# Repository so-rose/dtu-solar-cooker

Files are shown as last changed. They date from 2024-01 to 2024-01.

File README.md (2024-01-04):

# Solar Cooker
This is the repository for the project at the center of the DTU course 47203.
Highly WIP.

## Project Plan
See `design/plan.qmd` for GANTT chart and updated TODO list.

## Design
For design-phase, see `design/main.qmd`.
This is a Python-based Quarto document, which should also be readable as plain-text.

# Contributing
This project uses Quarto (<https://quarto.org/>), a FOSS tool for easily creating high-quality, reproducible, interactive documents, slideshows, websites, and more.

Quarto is cross-platform and integrates cleanly with many text editors.
If in doubt, try RStudio or VSCode.
See <https://quarto.org/docs/get-started/>

## Getting Started with Quarto
Quarto brings together the functionality of Jupyter notebooks, LaTeX mathematics typesetting, embeddable languages for ex. diagramming (<https://mermaid.js.org/syntax/gantt.html>), and automatic high-quality output to web, pdf, and many more.

This is all exposed using an almost-Markdown text format `.qmd`.

If any of this sounds familiar, it should be possible to be productive in Quarto within an hour:

- <https://quarto.org/docs/get-started/hello/text-editor.html>
- <https://quarto.org/docs/get-started/computations/text-editor.html>
- <https://quarto.org/docs/get-started/authoring/text-editor.html>

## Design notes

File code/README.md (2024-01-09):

# No-IDE Arduino

Works with Debian 11.

Install with
```bash
git clone --recurse-submodules https://github.com/so-rose/dtu-solar-cooker.git
```

# Setup
This project uses "Arduino Makefile" (<https://github.com/sudar/Arduino-Makefile>) to simplify cross-compiling and uploading `.ino` into a format supported by 
## Setup (Debian)
Install `arduino-mk` using:
```bash
sudo apt install arduino-mk
```

## Setup (Other)

For platform-specific configuration details, change the Makefile variables according to <https://github.com/sudar/Arduino-Makefile#usage>.

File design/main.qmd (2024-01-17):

---
title: "Solar Cooker Design"
date: "2024-01-01"
abstract: |
  Prototyping design for a solar cooker.
author:
  - name: Sofus Albert Høgsbro Rose (s174509)
    email: s174509@dtu.dk
    affiliation: 
      - name: Technical University of Denmark
        city: Kongens Lyngby
        url: dtu.dk

format:
  html:
    toc: true
    code-fold: true
    embed-resources: true
    #self-contained-math: true
    execute:
      output: "asis"
      warning: false
  pdf:
    toc: true
    execute:
      echo: false
      warning: false
      panel: "center"
---
\newpage

```{python}
from __future__ import annotations
from typing import Callable, Union
import itertools
import contextlib
from functools import reduce
from dataclasses import dataclass

import scipy as sc
import sympy as sp
import sympy.physics.units as spu
import numpy as np
import pandas as pd

import spb
import holoviews as hv
import hvplot.pandas

# HoloViews Configuration
hv.extension("matplotlib", logo=False)
hv.notebook_extension(display_formats=['html','png'])

# Sympy Printing Configuration
from IPython.display import display, display_latex
def disp(
	*exprs,
	numbering: bool = False,
	align_on: str | None = None,
):
	if align_on is not None:
		exprs_latex = (
			("\\begin{equation}" if numbering else "\\begin{equation*}")
			+ "\\begin{aligned}"
			+ "\\\\".join([
				sp.latex(
					expr,
					mode="plain"
				).replace(align_on, f" & {align_on}")
				for expr in exprs
			])
			+ "\\end{aligned}"
			+ ("\\end{equation}" if numbering else "\\end{equation*}")
		)

	else:
		exprs_latex = "\n\n".join([
			sp.latex(
				expr,
				mode="equation" if numbering else "equation*",
			)
			for expr in exprs
		])

	display_latex(exprs_latex, raw=True)
```

# General Design
The goal is to design a device, with the dimensions 300x300x300, which effectively uses solar light energy to heat water.

We will use a parabolic reflector to focus the maximal area of incoming solar power density onto a surface bounded by coiled water tubes.

# Design of Parabolic Reflector
We define the paraboloid reflector parametrically
```{python}
def paraboloid(
    u: sp.Symbol,
    theta: sp.Symbol,
    radius: float,
    height: float,
):
    return sp.Matrix([
        radius * sp.sqrt(u / height) * sp.cos(theta),
        radius * sp.sqrt(u / height) * sp.sin(theta),
        u,
    ])
```
and state its general form:
```{python}
u = sp.Symbol("u", real=True, positive=True)
theta = sp.Symbol("theta", real=True, positive=True)

disp(
    paraboloid(u, theta, sp.Symbol("r"), sp.Symbol("h"))
)
```

Our bounding box is $300 \text{mm}^3$, which we plug in directly as the diameter of the top ring
```{python}
#| echo: true

bound_side_length = spu.convert_to(
    300 * spu.mm,
    spu.meter,
)

diameter_reflector = bound_side_length
diameter_reflector_SI = diameter_reflector / spu.meter
height_reflector = bound_side_length / 8
disp(height_reflector)
```
and use to compute the particular parameterization of the reflector we need:
```{python}
# Computed
radius_reflector = diameter_reflector / 2

reflector = paraboloid(
    u,
    theta,
    radius_reflector / spu.meter,
    height_reflector / spu.meter,
)
disp(reflector)
```

The "focus point"
```{python}
height_focus_point = radius_reflector**2 / (4*height_reflector)
focus_point_reflector = sp.Matrix([
    0,
    0,
    height_focus_point,
])
disp(focus_point_reflector.n())
```
describes the destination point of all light reflected by the paraboloid.

Finally, we plot our desired reflector, with a small sphere around the focus point:
```{python}
u_s, v_s = sp.symbols("u_s v_s")
spb.graphics(
	spb.surface_parametric(
			*reflector,
			(u, 0, height_reflector / spu.meter),
			(theta, 0, 2*sp.pi),
			"expr",
			n=50,
	),
	spb.surface_parametric(
		focus_point_reflector[0] + (_r:=0.008) * sp.cos(u_s) * sp.sin(v_s),
		focus_point_reflector[1] + _r * sp.sin(u_s) * sp.sin(v_s),
		focus_point_reflector[2] / spu.meter + _r * sp.cos(v_s),
		(u_s, 0, 2*sp.pi),
		(v_s, 0, 2*sp.pi),
		"expr",
		n=20,
	),
	show=True,
	backend=spb.KB,
)
```

*We presume a choice of coordinate system that places the sun, a perfect directional light, directly above this construction.*

## Trapezoidal Discretization
To actually cheaply manufacture this mirror, we must create a discretization of this paraboloid into a number of small trapezoids.

In practice, we will cut/fabricate the trapezoids at this particular size, and attach precisely cut household Al foil (a cheap, non-rough, highly reflective material) to them. Then, they will be mounted into predefined elements of the paraboloid print.

Design TBD

# Energy Transfer
We describe the energy transfer properties, including the design of the heating container.

We introduce two variables to describe the (max) diameter of the heating container, and the flux power density of the solar light.
```{python}
diameter_container = sp.Symbol(
    "d_c", real=True, positive=True,
) * spu.meter
diameter_container_SI = diameter_container / spu.meter
#diameter_container = (diameter_reflector/8)
radius_container = diameter_container / 2

intensity_solar = sp.Symbol(
    "I_s", real=True, positive=True,
) * spu.watt/spu.meter**2  ## Surface Power Density
intensity_solar_SI = intensity_solar / (spu.watt/spu.meter**2)

## See the Solar Constant:
# - https://en.wikipedia.org/wiki/Solar_constant
# - https://en.wikipedia.org/wiki/Surface_power_density

disp(diameter_container / spu.meter, intensity_solar_SI)
```

## Design of Heating Container
We want our container to evenly receive heat energy reflected by the paraboloid reflector.
Thus, we define it to also be a paraboloid.

This method minimizes energy loss down to three primary sources:
- Shading due to the container blocking part of the parabolic reflector.
- Non-reflected light by the reflector.
- Non-absorbed light at the boundary of the container.

First, we define the actual area which is actively collecting solar energy as the "non-masked collection area":
```{python}
#| echo: true
total_collection_area = sp.pi * radius_reflector**2
masked_collection_area = sp.pi * radius_container**2

unmasked_collection_area = total_collection_area - masked_collection_area 

total_collection_power = sp.simplify(
	intensity_solar * total_collection_area
)

disp(
    unmasked_collection_area.n(2)
)
```

We use the unmasked collection area to compute the total power transmitted, in terms of the "solar constant" $I_s$ (**NOTE: This is some kind of integral of the sun's spectral power distribution.**)
```{python}
total_power = sp.simplify(
    intensity_solar * unmasked_collection_area * (2/3)
)
disp(
    sp.Eq(
        sp.Symbol("P_s"),
        total_power,
    )
)
```

Reasonably speaking, the **wattage per square meter** transmitted by the sun (aka. the value for $I_s$) can be fixed to $1.361\  \text{kWh}/\text{m}^2$.
This results in the following total incident solar power, as a function of the heating container diameter:
```{python}
disp(
    sp.Eq(
        sp.Function("P_s")(diameter_container_SI),
        total_power.subs({
					intensity_solar_SI: 1361, #spu.watt/spu.meter**2
					#diameter_container_SI: 0.08,
				}).n(),
    )
)
```

## Choice of Container Diameter
Small diameters are hard to work with in practice - but large diameters block too much power.
There is a subjectiveness to what the ideal choice.

Here's the graph of **wattage** as a function of container diameter:
```{python}
%matplotlib inline
spb.plot(
	total_power.subs({
		intensity_solar_SI: 1361, #spu.watt/spu.meter**2
	}) / spu.watt,
	(diameter_container_SI, 0, diameter_reflector_SI),
	show=True
)
```

Here's the graph of **retained energy factor** (percent/100) based on container diameter:
```{python}
%matplotlib inline
spb.plot(
	(total_power / total_collection_power).subs({
		intensity_solar_SI: 1361, #spu.watt/spu.meter**2
	}),
	(diameter_container_SI, 0, diameter_reflector_SI),
	show=True
)
```

Since we have **1/8 inch copper tubes** ($0.3175 \text{cm}$) available to us, we are not constrained by what we're wrapping around the heating container.

Thus, we select $5 \text{cm}$ as a reasonable tradeoff of fabrication simplicity relative to power loss.
The total incident power power at this value becomes:
```{python}
disp(
    sp.Eq(
        sp.Function("P_s")(3 * spu.cm),
        total_power.subs({
					intensity_solar_SI: 1361, #spu.watt/spu.meter**2
					diameter_container_SI: 0.03,
				}).n(),
    )
)
```

The retained power after shading using this choice of container diameter is just over 97 percent:
```{python}
diameter_container_chosen = 0.03 * spu.meter

disp(
	(total_power / total_collection_power).subs({
		intensity_solar_SI: 1361, #spu.watt/spu.meter**2
		diameter_container_SI: 0.05,
	}) * 100 * spu.percent
)
```

## Solving for the Container Height
Where exactly should the container sit?

First, we compute the angle from the upper ring of the reflector to the focus point
```{python}
angle_to_focus = sp.atan(
	(height_focus_point - height_reflector)
	/ radius_reflector
)
```

This angle can be used to form a right triangle between any edge point on the top reflector ring, the focus point, and the center of the reflector ring.

The height of this right triangle is the height of the ring.
Trigonometrically, it can be setup as
```{python}
height_container = sp.simplify(
	sp.tan(angle_to_focus) * (
		(diameter_reflector - diameter_container) / 2
	)
)

disp(height_container)
```
which computes out to
```{python}
chosen_height_container = height_container.subs({
	diameter_container_SI: sp.nsimplify(0.05),
})
disp(
	chosen_height_container.n()
)
```

Finally, when setting up the parameterization of the heating container, the container needs to be shifted up by the difference between the focus point and the reflector height.
```{python}
shift_reflector_to_container = height_focus_point - height_reflector
```

With this information, we create the paraboloid representing the container
```{python}
container = paraboloid(
    u,
    theta,
    2*radius_container / spu.meter,
    height_container / spu.meter,
) + sp.Matrix([
	0,
	0,
	shift_reflector_to_container / spu.meter,
])
disp(container)
```
chosen specifically to be
```{python}
chosen_container = container.subs({
	diameter_container_SI: sp.nsimplify(diameter_container_chosen/spu.meter),
})
disp(chosen_container)
```
and plot it visually:
```{python}
spb.plot3d_parametric_surface(
    list(reflector),
    list(chosen_container),
    (u, 0, height_reflector / spu.meter), (theta, 0, 2*sp.pi), "expr",
    n=50,
    backend=spb.KB,
)
```

## Computing Wire Properties
**TBD: Fix height of coil, compute wire length, compute contained volume.**

As mentioned, the wire in use is **1/8 inch copper tubes** ($0.3175 \text{cm}$).

Considering only the center of this wire for a moment, we parameterize it as a 1D curve:
```{python}
chosen_diameter_container_SI = sp.nsimplify(0.05)
chosen_radius_container_SI = chosen_diameter_container_SI/2

chosen_radius_container = chosen_radius_container_SI * spu.meter

coil_diameter = sp.nsimplify(0.05) * spu.meter
wire_diameter = spu.convert_to(
	sp.nsimplify(0.3175) * spu.cm,
	spu.meter,
)
wire_radius = wire_diameter / 2

chosen_container_radius = spu.meter * (
	chosen_diameter_container_SI/2 - sp.sqrt(
		chosen_container[0]**2
		+ chosen_container[1]**2
	).subs({
		u: (
			chosen_height_container + height_reflector
		) / spu.meter + (
			wire_diameter * u/(2*sp.pi)
		) / spu.meter
	}).simplify()
)

u = sp.Symbol("u", real=True, positive=True)
v = sp.Symbol("v", real=True, positive=True)
coiled_wire_surface = sp.simplify(
	sp.Matrix([
		chosen_container_radius*sp.cos(u) + (
			wire_radius*sp.cos(u)*sp.cos(v)
		),
		chosen_container_radius*sp.sin(u) + (
			wire_radius*sp.sin(u)*sp.cos(v)
		),
		chosen_height_container+height_reflector + (
			wire_diameter * u/(2*sp.pi)
		) + (
			wire_radius * sp.sin(v)
		),
	]) / spu.meter
)
disp(coiled_wire_surface)

spb.graphics(
	spb.surface_parametric(
		*reflector,
		(u, 0, height_reflector / spu.meter),
		(theta, 0, 2*sp.pi),
		"expr",
		n=50,
	),
	spb.surface_parametric(
		focus_point_reflector[0] + (_r:=0.004) * sp.cos(u_s) * sp.sin(v_s),
		focus_point_reflector[1] + _r * sp.sin(u_s) * sp.sin(v_s),
		focus_point_reflector[2] / spu.meter + _r * sp.cos(v_s),
		(u_s, 0, 2*sp.pi),
		(v_s, 0, 2*sp.pi),
		"expr",
		n=20,
	),
	spb.surface_parametric(
		*chosen_container,
		(u, 0, height_reflector / spu.meter),
		(theta, 0, 2*sp.pi),
		"expr",
		n=100,
	),
	spb.surface_parametric(
		*coiled_wire_surface,
		(u, 0, 10*sp.pi), (v, 0, 10*sp.pi), "expr",
		n=100,
	),
	backend=spb.KB,
)
```

# Pressure Flow Rate

We compute the water pressure
```{python}

```

# Fabrication Procedure
- [x] Compute required length of 1/8 inch copper tubing for wrapping around, including space for outlet and inlet.
- [x] Compute volume contained within each segment of tubing, aka. measure the thickness.
- [x] Compute number and size of mirror (glass) trapezoids.
- [x] Compute printable geometry for the reflector, including slots for inserting trapezoid mirrors, including a mounting mechanism for the container, including a hole in the bottom for water outlet, and possibly including a doughnut-shaped spot for upper water storage.
- [x] Compute printable geometry for the container, including slots for the tubing and the mounting mechanism.
- [x] Compute a heatmap on the container of areas where trapezoid-reflected solar intensities are non-uniform (as the perfect curve)
- [ ] Correct actual power transferred to water in each region of tubing, considering the simulated trapezoidal discretization.
- [x] Choose an adhesive (?) effective for the mirrors and for the tubes, which can handle temperatures up to 125C.
- [ ] Determine a mechanism for flow control at the outlet, ex. software flow control?

- [ ] Fabricate the mirror, container, water containers, and try mounting it all.
- [ ] Try running water through the entire mechanism, to make sure it can do that.
- [ ] Spray-paint the tubing black (if it isn't already absorbive).

- [ ] Include computations describing the efficiency of the reflector and the efficiency of the absorbive copper tubing.
	- [ ] Can we borrow a spectrometer to characterize the two materials we end up with? Maybe even at the particular incident angles?

- [ ] Try a FEM simulation of the final setup to solve for heat transfer over time.

*Maybe we should just give the reflector feet and just pseudo-submerse it in the lower water collector?*

*The water container could also be a 3D-printed thing; however, it will need waterproofing. Much better idea; it could be better to just use something normal. Literally a plastic bag or bowl or something.*

*How will we know it works? 0.5L of water at 21C would, over the course of 15minutes, require 79 watts to reach a temperature of 55C. Since we know the incident wattage as solar light intensity, the final temperature will tell us how we did in terms efficiency.*

After print
- [ ] Another motor for the flow rate
- [ ] Empirically measure
- [ ] Print an output flow control

- [ ] Cold water towers (cans?)
- [ ] Hot water container
Don't boil things!

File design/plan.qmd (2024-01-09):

---
title: "Solar Cooker Project Planning"
date: "2024-01-04"
abstract: |
  Our approach to the Solar Cooker project.
#author:
#  - name: Sofus Albert Høgsbro Rose (s174509)
#    email: s174509@dtu.dk
#    affiliation: 
#      - name: Technical University of Denmark
#        city: Kongens Lyngby
#        url: dtu.dk

format:
  html:
    toc: true
    code-fold: true
    embed-resources: true
    #self-contained-math: true
    execute:
      output: "asis"
      warning: false
  pdf:
    toc: true
    execute:
      echo: false
      warning: false
      panel: "center"
  ipynb:
    toc: true
    execute:
      echo: true
      warning: false
---
\newpage

# GANTT Chart
This is the overarching plan (group )
```{mermaid}
gantt
    title Design-Build 3 Plan
    dateFormat YYYY-MM-DD
    section Simulation
        Design :2023-01-01, 3d
        Thermal :2d
        MVP Validation :2023-01-07, 2d
        Validation :2023-01-12, 4d
    section Fabrication
        Geometry :2023-01-05, 1d
        MVP :3d
        Production :5d
    section Control
        Temp :2023-01-08, 2d
        Shaders :2d
        Instrument :2023-01-09, 5d
    section Report
        Preliminary :2023-01-02, 7d
        Body :7d
        Polish :2d
        Exam :1d
```

# Big Plan
**Simulation**

- [ ] Design: How is it going to work? From first principles.
- [ ] Thermal Simulation: Execute a heat transfer simulation.
- [ ] MVP Validation: Validate that the simulation (and presumptions therein) was done accurately.
- [ ] Validation: Validate that the simulation (and presumptions therein) was done accurately.

**Fabrication**

- [ ] Geometry: Design the 3D-printable model.
- [ ] MVP: Fabricate a first attempt, which should work minimally. **Test with artificial sun at the end**.
- [ ] Production: Fabricate the final product.

**Control**

- [ ] Temperature Sensor: Install the temperature sensor.
- [ ] Shaders: Install the shader control.
- [ ] Instrument: Instrument real-time data, for internal use and for export / graphing.

**Report**

- [ ] Preliminary: The design document (`.qmd`) will later become the report.
- [ ] Body: Writing happens parallel to post-MVP refinements.
- [ ] Polish: Refine report and produce a slideshow variant.
- [ ] Exam: Final preparations and exam.

## Fabrication List
- [ ] Reflector: High-R parabolic shape.
- [ ] Container: Internal parabolic boundary is 3D-printed, around which liquid tubes are wrapped, which in turn are painted with a high-A material that minimizes blackbody radiation loss.
- [ ] Fabrication Device

## Shopping List
- [ ] 1/8 Inch Copper Tube
- [ ] Black Spray Paint

- [ ] Exact knife
- [ ] Spray glue

- [ ] Cold water tower
- [ ] Hot water container

- [ ] Funnel (for flow test)

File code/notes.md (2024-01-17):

# Experiment 0
`experiment_0`: Cold water temperature.

# Experiment 1
`experiment_1`: Hot water temperature (full flow) after heating for 1min

Pre-Measure:
- Cold water temp
- Hot water temp

Procedure:
- Plug Outlet w/Plug
- Video Start
- Fill 20mL Fluid into Cold Water Container
- Insert Thermometer into Hot Water Container water temperature
- Simultaneously:
	- Insert Contraption
	- Start Timer
	- Close Hood
- @ Timer=1min
	- Open Hood
	- Remove Contraption
	- Stop Timer
	- Close Hood
- Simultaneously:
	- Start Thermometer Recording
	- Unplug Outlet
	- Start Timer
- @ Water Flow Done
	- Stop Timer

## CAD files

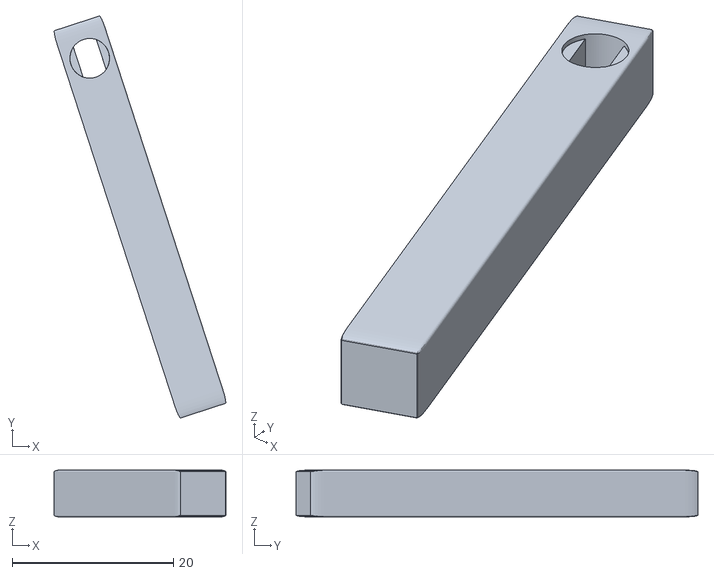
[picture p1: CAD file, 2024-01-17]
prints/lever/lever_2.stl
21.3 x 49.9 x 5.80

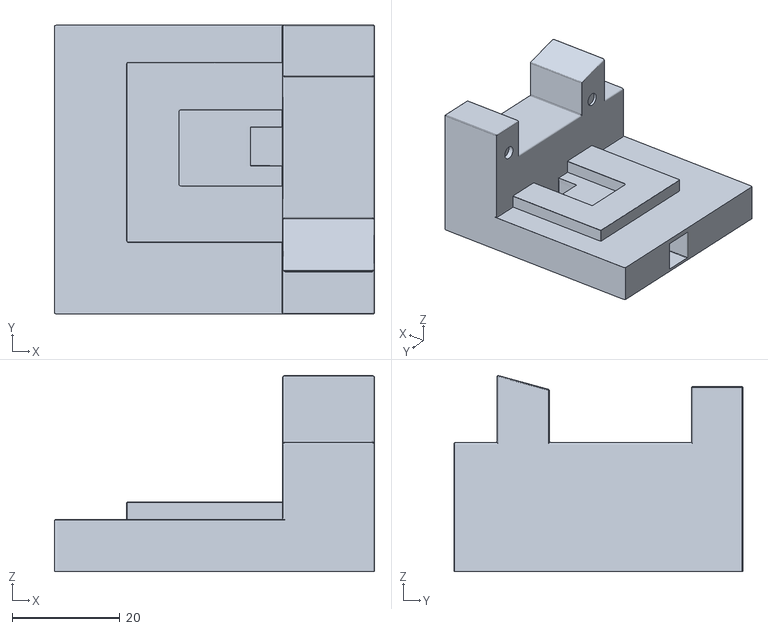
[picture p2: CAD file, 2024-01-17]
prints/mount/mount_1.stl
59.3 x 53.6 x 36.3

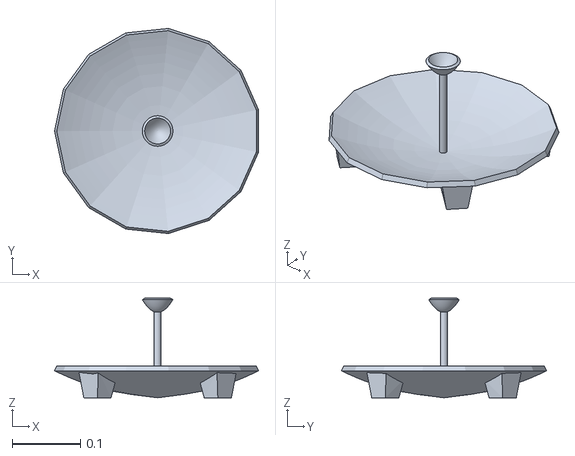
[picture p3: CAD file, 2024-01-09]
prints/reflector/reflector_1.stl
0.299 x 0.3 x 0.146

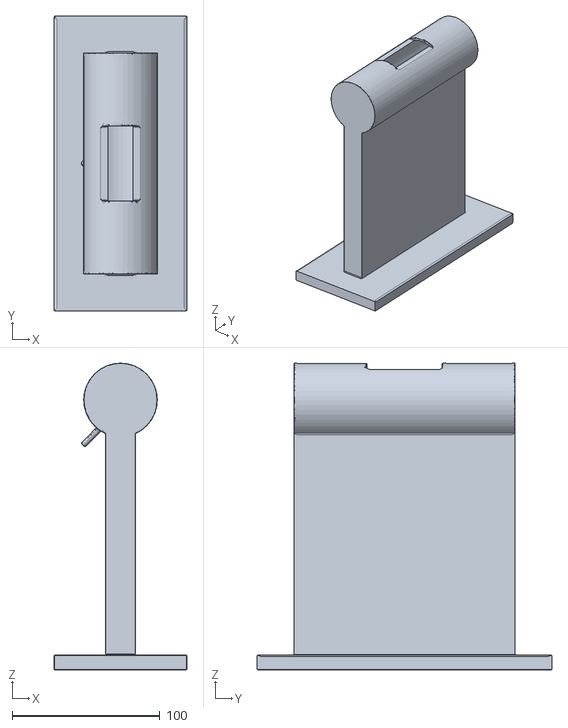
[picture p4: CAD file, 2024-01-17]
prints/water_tower/water_tower_1.stl
90.0 x 200.0 x 208.0

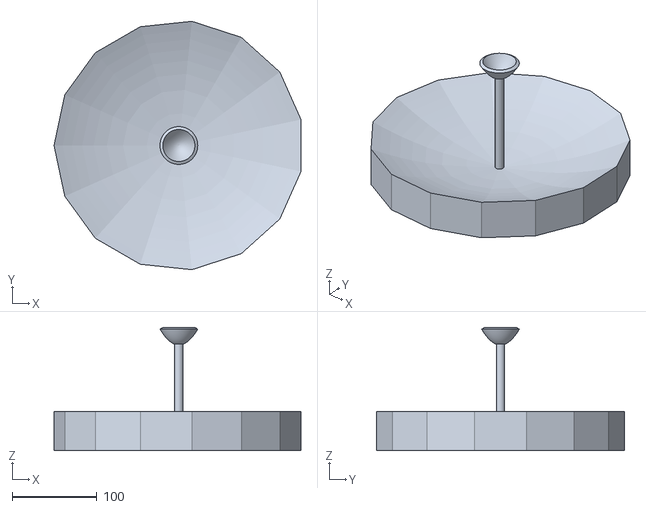
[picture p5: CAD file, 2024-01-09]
prints/reflector/reflector_2.stl
292.2 x 293.8 x 145.8

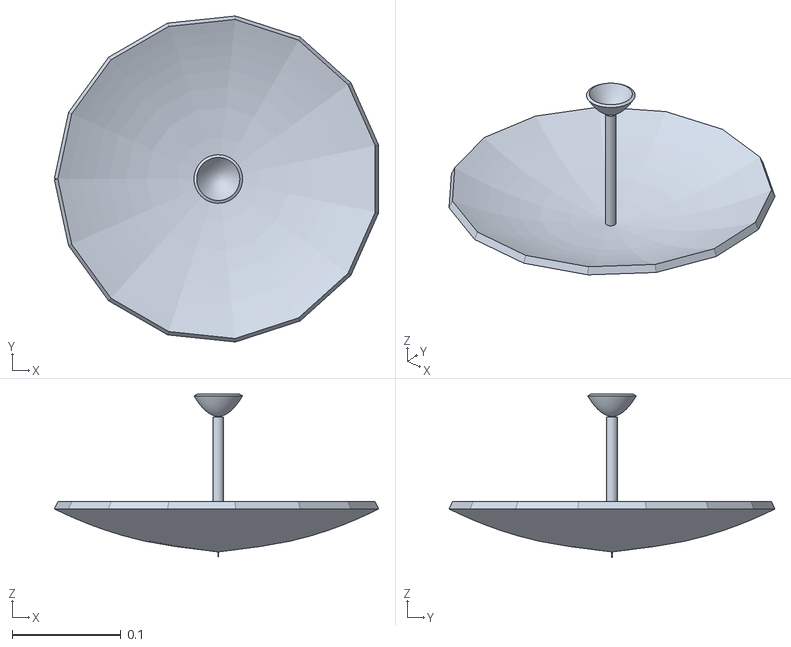
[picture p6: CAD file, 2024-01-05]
prints/reflector/reflector_0.stl
0.299 x 0.3 x 0.179

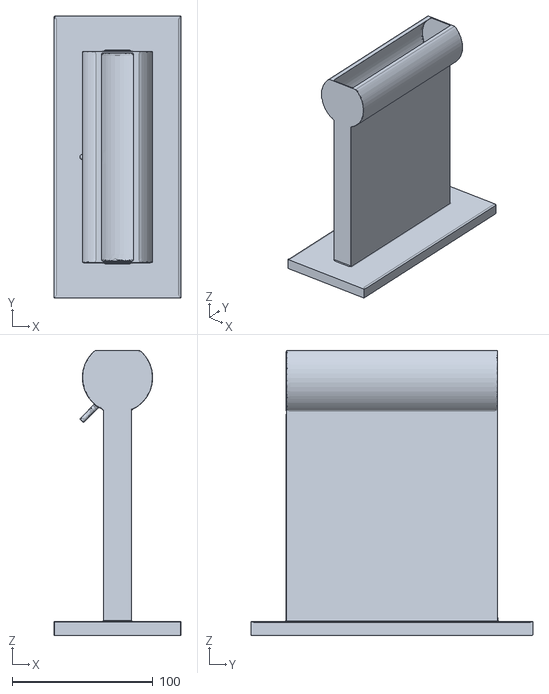
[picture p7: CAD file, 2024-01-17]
prints/water_tower/water_tower_2.stl
90.0 x 200.0 x 202.2

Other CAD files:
prints/lever/lever_1.stl
prints/water_tower/water_tower_0.stl
prints/water_tower/print.obj
print.blend
prints/print.blend

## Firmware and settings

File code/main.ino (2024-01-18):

#include <Stepper.h>
#include <OneWire.h>
#include <DallasTemperature.h>
#include <NonBlockingDallas.h>

//####################
// - Hardware Configuration
//####################
#define BAUD_RATE 9600
// - Byte Transfer Rate for Serial Interface

#define PIN_ONEWIRE 4
// - Pin for the Temperature Sensor(s)

#define PIN_STEPPER_1 8
#define PIN_STEPPER_2 10
#define PIN_STEPPER_3 9
#define PIN_STEPPER_4 11
// - Pins for the Step Motor (**Presume + is CCW**)
// - ---------------------------
// - Stepper.h[4] -> 8 -> IN1 -> Blue -> Motor{4}
// - Stepper.h[2] -> 9 -> IN2 -> Pink -> Motor{2}
// - Stepper.h[3] -> 10 -> IN3 -> Yellow -> Motor{3}
// - Stepper.h[1] -> 11 -> IN4 -> Orange -> Motor{1}
// - _Simply invert Stepper.h Indices to make CW the + direction._
// - ---------------------------
// - See <https://components101.com/motors/28byj-48-stepper-motor>


//####################
// - Configuration - Temperature Sensor
//####################
#define LED_MOTOR_LIGHT_TEMP 30.0
// - Temperature Threshold for LED Activation
// - Degrees Celcius.

#define TEMP_RESOLUTION NonBlockingDallas::resolution_11
// - Temperature Data Resolution (# of precision bits) vs. Computation Time
// - ---------------------------
// - 9 bit       93 ms
// - 10 bit      187 ms
// - 11 bit      375 ms
// - 12 bit      750 ms
// - See <https://github.com/Gbertaz/NonBlockingDallas>

#define TEMP_SAMPLE_RATE 500
// - Temperature Data Sample Rate
// - **Must be > Conversion Time for Chosen Resolution**.
// - Milliseconds. 


//####################
// - Configuration - Step Motor
//####################
#define STEPS_PER_REV 2038
// - Motor Steps per Full Revolution (360 degrees)
// - Property of Motor

#define RPM 10
// - Speed of Motor (in Revolutions per Minute)

//#define DEG_FOR_SHADER_TOGGLE 81.8753
#define DEG_FOR_SHADER_TOGGLE 92
// - Degrees Rotation to Open/Close Shader (Computed empirically)


//####################
// - Utilities - Step Motor
//####################
#define DEG_TO_STEPS(deg) ( (long)(deg * (double)STEPS_PER_REV / 360.0) )
// - Degrees are given as doubles, steps must be given as a long


//####################
// - Initialization
//####################
Stepper stepper(STEPS_PER_REV, PIN_STEPPER_1, PIN_STEPPER_2, PIN_STEPPER_3, PIN_STEPPER_4);

OneWire oneWire(PIN_ONEWIRE);
DallasTemperature sensor(&oneWire);
NonBlockingDallas sensorNoBlock(&sensor);


//####################
// - Global State
//####################
bool led_on = false;
bool isShaderOpen = false;



//####################
// - Reporters
//####################
void report_temp(float temperature){
	Serial.print("C: ");
	Serial.print(temperature);
	Serial.print("\n");
}

void report_rot(long steps){
	Serial.print("R: ");
	Serial.print(steps);
	Serial.print("\n");
}



//####################
// - Shader Control
//####################
void openShaders() {
	if (!isShaderOpen) {
		report_rot(-DEG_TO_STEPS(DEG_FOR_SHADER_TOGGLE));
		stepper.step(-DEG_TO_STEPS(DEG_FOR_SHADER_TOGGLE));
		isShaderOpen = true;
	}
}
void closeShaders() {
	if (isShaderOpen) {
		report_rot(DEG_TO_STEPS(DEG_FOR_SHADER_TOGGLE));
		stepper.step(DEG_TO_STEPS(DEG_FOR_SHADER_TOGGLE));
		isShaderOpen = false;
	}
}



//####################
// - Temperature Readout
//####################
void handleIntervalElapsed(float temperature, bool valid, int deviceIndex){
	report_temp(temperature);
	// Set LED Temperature Indicator
	if (temperature >= LED_MOTOR_LIGHT_TEMP && !led_on) {
		led_on = true;
		digitalWrite(LED_BUILTIN, HIGH);
		openShaders();
	} else if (temperature < LED_MOTOR_LIGHT_TEMP && led_on) {
		led_on = false;
		digitalWrite(LED_BUILTIN, LOW);
		closeShaders();
	}
}


//####################
// - Startup and Main Loop
//####################
void setup() {
  Serial.begin(BAUD_RATE);
  pinMode(LED_BUILTIN, OUTPUT);
  stepper.setSpeed(RPM);

  sensorNoBlock.begin(TEMP_RESOLUTION, NonBlockingDallas::unit_C, TEMP_SAMPLE_RATE);
  sensorNoBlock.onIntervalElapsed(handleIntervalElapsed);
}

void loop() {
	sensorNoBlock.update();  // Possibly Read Temperature
	
	if (Serial.available() > 0) {
		String command = Serial.readString();
		command.trim();  // Get Rid of Leading/Trailing Whitespace (\n, \r, other trash)
		
		if (command == "shader open") {
			openShaders();
		} else if (command == "shader close") {
			closeShaders();
		} else if (command.startsWith("motor inc ")) {
			long increment_steps = command.substring(10).toInt();
			report_rot(increment_steps);
			stepper.step(increment_steps);
		} else if (command.startsWith("motor rot ")) {
			double increment_degrees = command.substring(10).toDouble();
			report_rot(DEG_TO_STEPS(increment_degrees));
			stepper.step(DEG_TO_STEPS(increment_degrees));
		} else if (command.startsWith("motor test")) {
			stepper.step(1000);
			delay(500);
			stepper.step(-1000);
		}
	}
}

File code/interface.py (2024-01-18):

#!/usr/bin/env python3

import os
import sys
import time
import readline
import random
import signal
import datetime as dt
from pathlib import Path

try:
	import serial 
except ImportError:
	print("To run the Solar Tap CLI, please install the `pyserial` library.")
	print("\tPyPi: https://pypi.org/project/pyserial/")
	print("\tDebian/Ubuntu: (sudo) apt install python3-serial")
	sys.exit(1)

####################
# - Constants
####################
PATH_ROOT = Path(__file__).resolve().parent
PATH_EXP = PATH_ROOT / "exp" / dt.date.today().isoformat()

PATH_EXP_TEMP = lambda experiment_number: (
	PATH_EXP / str(experiment_number) / "temp.txt"
)
PATH_EXP_ROT = lambda experiment_number: (
	PATH_EXP / str(experiment_number) / "rot.txt"
)

PORT = "/dev/ttyACM0"
BAUD_RATE = 9600


####################
# - Global State
####################
FIRST_CLI_RUN = True
CLI_ACTIVE = False

EXPERIMENT_ACTIVE = False
EXPERIMENT_NUMBER = None

TEMP_SAMPLE = 0
ROT_SAMPLE = 0


####################
# - Mode Enable/Disable
####################
def enable_experiment(experiment_number: int):
	global CLI_ACTIVE
	global EXPERIMENT_ACTIVE
	global EXPERIMENT_NUMBER
	global TEMP_SAMPLE
	global ROT_SAMPLE
	
	print(f"[Enable] Experiment {experiment_number}...")
	EXPERIMENT_ACTIVE = True
	EXPERIMENT_NUMBER = experiment_number
	TEMP_SAMPLE = 0
	ROT_SAMPLE = 0
	disable_cli()
	
def disable_experiment():
	global EXPERIMENT_ACTIVE
	global EXPERIMENT_NUMBER
	
	print(f"[Disable] Experiment {EXPERIMENT_NUMBER}...")
	EXPERIMENT_ACTIVE = False
	EXPERIMENT_NUMBER = None


def enable_cli():
	global CLI_ACTIVE
	
	print("[Enable] CLI...")
	CLI_ACTIVE = True

def disable_cli():
	global CLI_ACTIVE
	
	print("[Disable] CLI...")
	CLI_ACTIVE = False

def quit_program():
	print("[Exiting]")
	sys.exit(0)

def cli_help():
	return """
Welcome to the Solar Tap CLI ("Command Line Interface")!
The following is a reference to available commands (type without ``, followed by "ENTER"):


`q`, `quit`: Quit the program.

CTRL+C: From monitoring mode, enable the CLI. From the CLI, quit the program.
	-> CTRL+C from monitoring mode will always disable any active experiment.

`monitor`: Disable the CLI mode, and return to monitoring mode.
	-> Messages received while in the CLI were buffered, and are replayed.


`enable experiment <number>`: Enable monitoring of an experiment, which will write data to dedicated files.
	-> Experiment recordings can be found at './exp/<today>/<number>/' (relative to this script) as 'temp.txt' and 'rot.txt'
	-> Recording format is '<sample_count>|<sample_datetime_iso8601>|<sample_value>".
	-> One line per sample


`motor inc <steps>`: Increment the step motor by a number of steps (steps are specific to motor model).
	-> Use negative steps to rotate the other way.

`motor rot <degrees>`: Increment the step motor by a number of degrees (degrees to steps are hard-coded on the microcontroller).
	-> Use negative degrees to rotate the other way.


`shader open`: Open the solar tap shaders, by rotating the motor a hard-coded number of degrees.
	-> When the shaders are already open, nothing happens.
	-> Whenever powering on the solar tap, it is presumed that the shaders are closed.

`shader close`: Close the solar tap shaders, by rotating the motor a hard-coded number of degrees.
	-> When the shaders are already closed, nothing happens.
	-> Whenever powering on the solar tap, it is presumed that the shaders are closed.


`compile`: Flash new firmware for the Solar Tap, by running 'make'.
	-> The command 'make' must work without this script.
	-> You must run this script from the directory that you run 'make' in.

`flash`: Flash new firmware to the Arduino, by running 'make upload'.
	-> See `compile`.
"""


####################
# - Device Actions
####################
def motor_inc(steps_str: str):
	"""Increment the motor by a given number of steps."""
	steps = int(steps_str)
	device.write(f"motor inc {steps}".encode())

def motor_rot(steps_str: str):
	"""Increment the motor by a given number of degrees."""
	degrees = float(steps_str)
	device.write(f"motor rot {degrees}".encode())


def shader_open():
	"""Open the shader by rotating a hard-coded amount."""
	device.write("shader open".encode())

def shader_close():
	"""Close the shaders by rotating a hard-coded amount."""
	device.write("shader close".encode())


####################
# - Signal Handling
####################
def on_sigint(sig, frame):
	"""Run when receiving SIGINT.
	"""
	global CLI_ACTIVE
	global TEMP_SAMPLE
	global ROT_SAMPLE
	
	# Newline to Jump Past ^C
	print()
	
	if EXPERIMENT_ACTIVE:
		disable_experiment()
	
	# Disable Experiment
	if CLI_ACTIVE:
		quit_program()
	else:
		enable_cli()



####################
# - Testing Serial Device
####################
class TestingSerialDevice:
	def __init__(self, port=None, baudrate=None, timeout=None):
		print("[DEBUG] Initializing Fake (Test) Serial Device:")
		print(f"\tport = {port}")
		print(f"\tbaudrate = {baudrate}")
		print(f"\ttimeout = {timeout}")
		print()
	
	def readline(self):
		time.sleep(0.5)
		if random.random() > 0.1:
			return "C: 1000.0".encode()
		else:
			return "R: 10".encode()
	
	def write(self, msg: bytes):
		print("Wrote to Device:", repr(msg))


####################
# - main()
####################
if __name__ == "__main__":
	# Attach Signal Handlers
	signal.signal(signal.SIGINT, on_sigint)
	
	print(f"""Welcome to the Solar Tap Interface!

The program will now attempt to connect to a Solar Tap device with the following settings:

  PORT: {PORT}
  BAUD_RATE: {BAUD_RATE}

If you're getting an error message, please adjust these constants in the source code of this program ('interface.py').
You should make use of the 'pyserial' documentation: <https://pyserial.readthedocs.io/en/latest/shortintro.html>.
""")
	
	# Connect to Device
	if len(sys.argv) > 1 and sys.argv[1] == "test":
		device = TestingSerialDevice(
			port=PORT,
			baudrate=BAUD_RATE,
			timeout=0.1,
		)
	else:
		device = serial.Serial(
			port=PORT,
			baudrate=BAUD_RATE,
			timeout=0.1,
		)
	
	print(f"[Connected] Device on port {PORT} with baudrate {BAUD_RATE}!")
	print()
	# Basic Usage
	print("""The program is now monitoring and printing events from the Solar Tap.
The data format is interpreted as follows:
- 'C: <number>': This denotes a measurement by the temperature sensor, in degrees celcius.
- 'R: <number>': This denotes a rotation requested of the step motor, in motor steps (steps -> degrees depends on the motor).
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

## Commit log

2024-01-04 feat: Streamlined prototype and plan.
2024-01-05 feat: First print!
    [print.blend, print_0.stl]
2024-01-09 feat: Added fun arduino code.
    [print.blend, print_1.stl, print_2.stl]
2024-01-17 feat: Added latest code and prints.
    [lever_1.stl, lever_2.stl, mount_1.stl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]
2024-01-18 feat: Cooler interface.py
    [print.blend]
